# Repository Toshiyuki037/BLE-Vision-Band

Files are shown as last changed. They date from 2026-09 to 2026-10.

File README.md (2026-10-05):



<!-- BADGES -->

<p align="center">
  
  
  
  
</p>

<br />

<!-- TITLE -->

<div align="center">
  <h1>WBLE Vision Band</h1>
  <p><strong>Embedded BLE Vision System with Haptic Feedback</strong></p>

  <p>
    A wrist-mounted system that performs on-device image recognition and communicates results through real-time haptic feedback.
  </p>

  <br />

<a href="#">🎥 View Demo (Coming Soon)</a>

</div>

---

## 📌 Overview

Vision-Band is a wearable embedded system designed to explore on-device perception in resource-constrained environments.

Motivated by the limitations of the Even Realities G2 Frames—specifically the lack of an integrated camera—this project implements a modular vision pipeline paired with a haptic feedback interface for real-time, non-visual interaction.

---

## 🧠 System Architecture

```bash
[Camera] → [nRF5340 MCU] → [Processing / ML] → [DRV2605L] → [Vibration Motor]
                               ↓
                             [BLE]
```

* SPI camera streams image data to MCU
* MCU performs lightweight processing / inference
* Haptic driver converts results into vibration feedback
* BLE enables debugging + external communication

---

## 🔧 Hardware Components

* NRF5340-DK — main MCU + BLE
* Arducam Mega 5MP SPI Camera — image capture
* DRV2605L — haptic driver
* 3V vibration motor — feedback output
* Li-ion battery (500mAh) — power
* TP4056 — charging module

---

## DOCUMENTATION (BOM)

A dated and recorded log of all my research and development.
👉 https://app.notion.com/p/Vision-Band-3348546487d380519d59cf720e47a7b5

---

## 📦 Bill of Materials (BOM)

A detailed breakdown of all components, costs, and sourcing is available below:

👉 https://docs.google.com/spreadsheets/d/1EQedtdF9KUZCxSDgVT32OZnp6HhoeuN5VWY41QO01Ro/edit?usp=sharing

* Includes part numbers, suppliers, and prototyping cost (~$187)
* Documents full hardware stack for reproducibility

---

## ⚙️ Software Stack

* Embedded firmware (C/C++)
* SPI image acquisition pipeline
* I²C haptic control (DRV2605L)
* BLE communication (Nordic SDK)
* Lightweight image recognition (TinyML / rule-based)

---

## 🚀 Features

* On-device image capture and processing
* Real-time haptic feedback output
* BLE-enabled communication interface
* Fully self-contained wearable prototype
* End-to-end embedded system (hardware + firmware integration)

---

## 📊 Challenges & Engineering Tradeoffs

* **Memory constraints:** Limited RAM for image buffering
* **Bandwidth limits:** SPI camera throughput bottlenecks
* **Power system limitations:** TP4056 lacks load sharing
* **Compute vs latency:** Balancing ML accuracy and responsiveness

---

## 🔋 Power Considerations

* Powered by 3.7V Li-ion battery (500mAh)
* Charging via TP4056
* System currently optimized for prototyping, not all-day wearable use

---

## 🛠️ Getting Started

### Prerequisites

* Arduino IDE or Nordic SDK
* USB connection for NRF5340-DK
* Basic embedded development setup

### Installation

```bash
git clone https://github.com/Toshiyuki037/BLE-Vision-Band.git
```

1. Open firmware in IDE
2. Connect hardware components
3. Flash firmware to board
4. Power via battery + charging module

---

## 📁 Project Structure

```bash
/firmware      → Embedded code  
/hardware      → Schematics / BOM  
/docs          → Design notes  
```

---

## 🗺️ Roadmap

* [x] Hardware integration
* [x] Camera + MCU interface
* [ ] Image recognition optimization
* [ ] Power system redesign
* [ ] Custom PCB
* [ ] Wearable enclosure

---

## 📜 License

Distributed under the MIT License.

---

## 📬 Contact

GitHub: https://github.com/Toshiyuki037

Project Link:
https://github.com/Toshiyuki037/BLE-Vision-Band

---

<p align="center">↑ Back to top</p>

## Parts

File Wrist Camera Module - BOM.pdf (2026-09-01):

Assembly Name: Wrist Mounted Embedded BLE Image Recognition Module | Quantity Total: | 6
| Date: 4/23/26 | | | | | Prototyping Cost: 187.86
Final | Prototyping | Part ID | Part Name | URL | Quantity | Cost | BOM Notes
| * | KTO-M101949W | Micro DC Vibrating Motor : DC 3V | | 1 | 6.99 | ERM vibration motor; driven by DRV2605L
* | TP4056 | Type-C USB Charging Module 5V 1A | https://www.amazon.com/gp/product/B08FSRV7GS/ref=ox_sc_act_title_2?smid=A39S0U3UP1U7UG&th=1 1 | 5.99 | Li-ion charger; no load sharing/power path
* | RB-Adu-237 | Arducam Mega 5MP SPI Camera | https://www.amazon.com/gp/product/B0BW7MDVHK/ref=ox_sc_act_title_3?smid=A2IAB2RW3LLT8D&th=1 1 | 34.99 | SPI camera; requires downsampling + careful memory use
* | NRF5340-DK | Nordic Semiconductor Development Kit | https://www.amazon.com/gp/product/B0FCVL5JVT/ref=ox_sc_act_title_6?smid=A3N9748LE8DD6Y&psc=1 1 | 119.99 | Main MCU + BLE; dev board (not final form factor)
* | DRV2605L | Haptic Motor Controller | https://www.amazon.com/gp/product/B083G1MCYZ/ref=ox_sc_act_title_5?smid=A2KRDQ1AI5Y5G6&psc=1 1 | 11.95 | I²C haptic driver for vibration motor (ERM)
* | 1528-1841-ND | BATTERY LITH-ION 3.7V 500MAH | https://www.digikey.com/en/products/detail/adafruit-industries-llc/1578/5054539 1 | 7.95 | Main power source; limited runtime

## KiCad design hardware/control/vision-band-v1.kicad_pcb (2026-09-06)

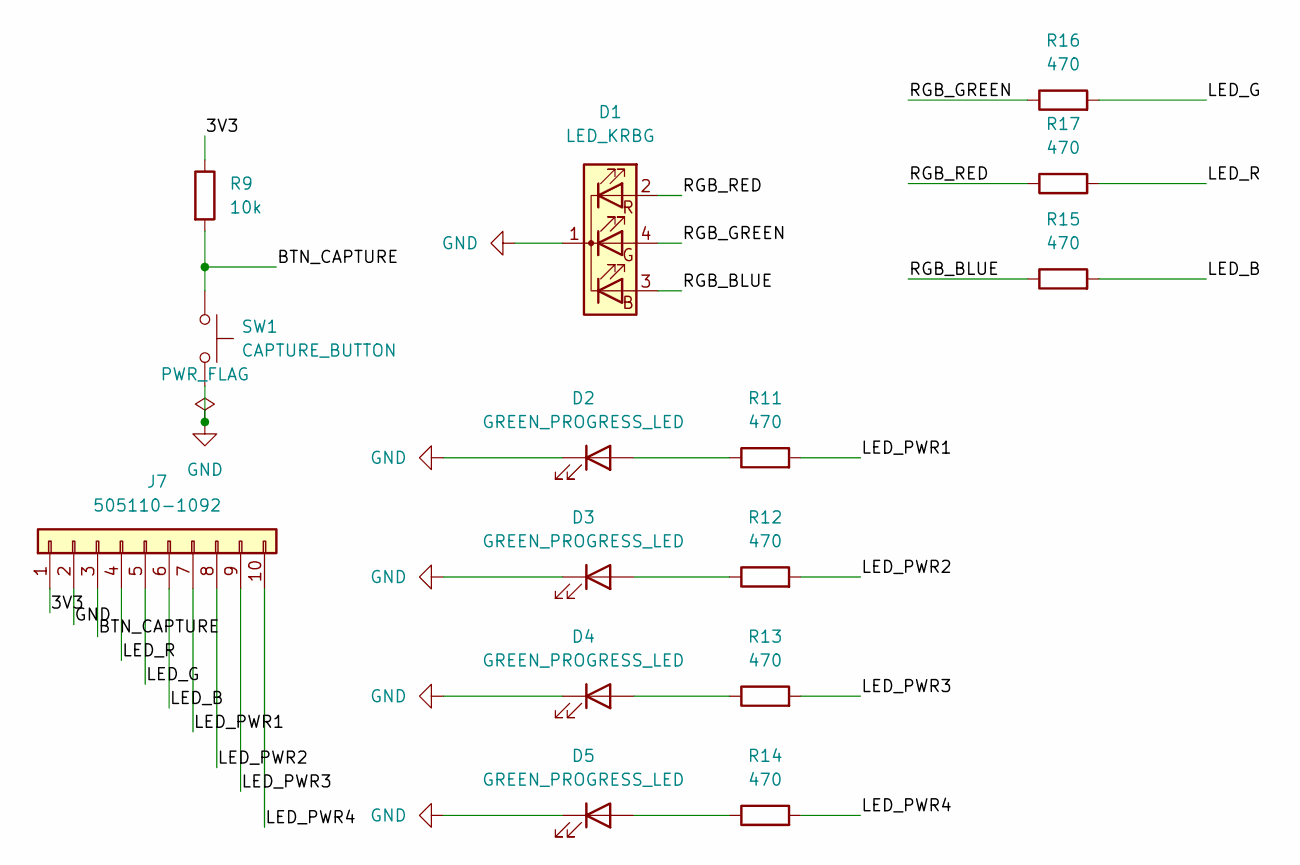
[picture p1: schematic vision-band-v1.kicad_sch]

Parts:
D1: LED_KRBG; APTF1616SEJ3ZGGVBDC_KNB; MPN APTF1616LSEKJ3ZGKQBC
D2, D3, D4, D5: GREEN_PROGRESS_LED; LED_0603_1608Metric; MPN APT1608LZGCK
J7: 505110-1092; MOLEX_5051101092; MPN 505110-1092
R9: 10k; R_0603_1608Metric; MPN RC0603FR-0710KL
R11, R12, R13, R14, R15, R16, R17: 470; R_0603_1608Metric; MPN RC0603FR-07470RL
SW1: CAPTURE_BUTTON; SW_SPST_TL3305A; MPN TL3305AF160QG

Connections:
/3V3: J7.1, R9.1
/BTN_CAPTURE: J7.3, R9.2, SW1.1
/LED_B: J7.6, R15.2
/LED_G: J7.5, R16.2
/LED_PWR1: J7.7, R11.2
/LED_PWR2: J7.8, R12.2
/LED_PWR3: J7.9, R13.2
/LED_PWR4: J7.10, R14.2
/LED_R: J7.4, R17.2
/RGB_BLUE: D1.3 (BA), R15.1
/RGB_GREEN: D1.4 (GA), R16.1
/RGB_RED: D1.2 (RA), R17.1
GND: D1.1 (K), D2.1 (K), D3.1 (K), D4.1 (K), D5.1 (K), J7.2, SW1.2
unnamed: D2.2 (A), R11.1
unnamed: D3.2 (A), R12.1
unnamed: D4.2 (A), R13.1
unnamed: D5.2 (A), R14.1

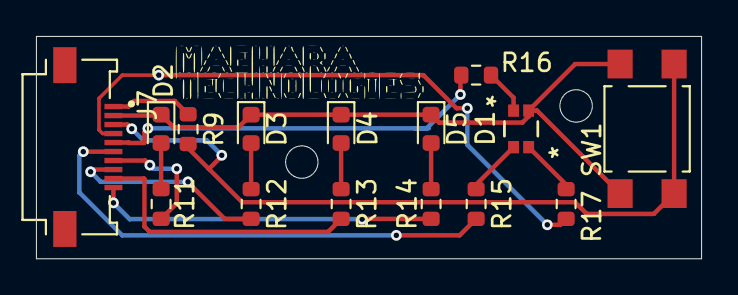
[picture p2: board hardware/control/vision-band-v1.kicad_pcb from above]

Board: 2 copper layers, 37.0 x 12.3 mm, 15 parts (0 on the bottom side), 17 nets.

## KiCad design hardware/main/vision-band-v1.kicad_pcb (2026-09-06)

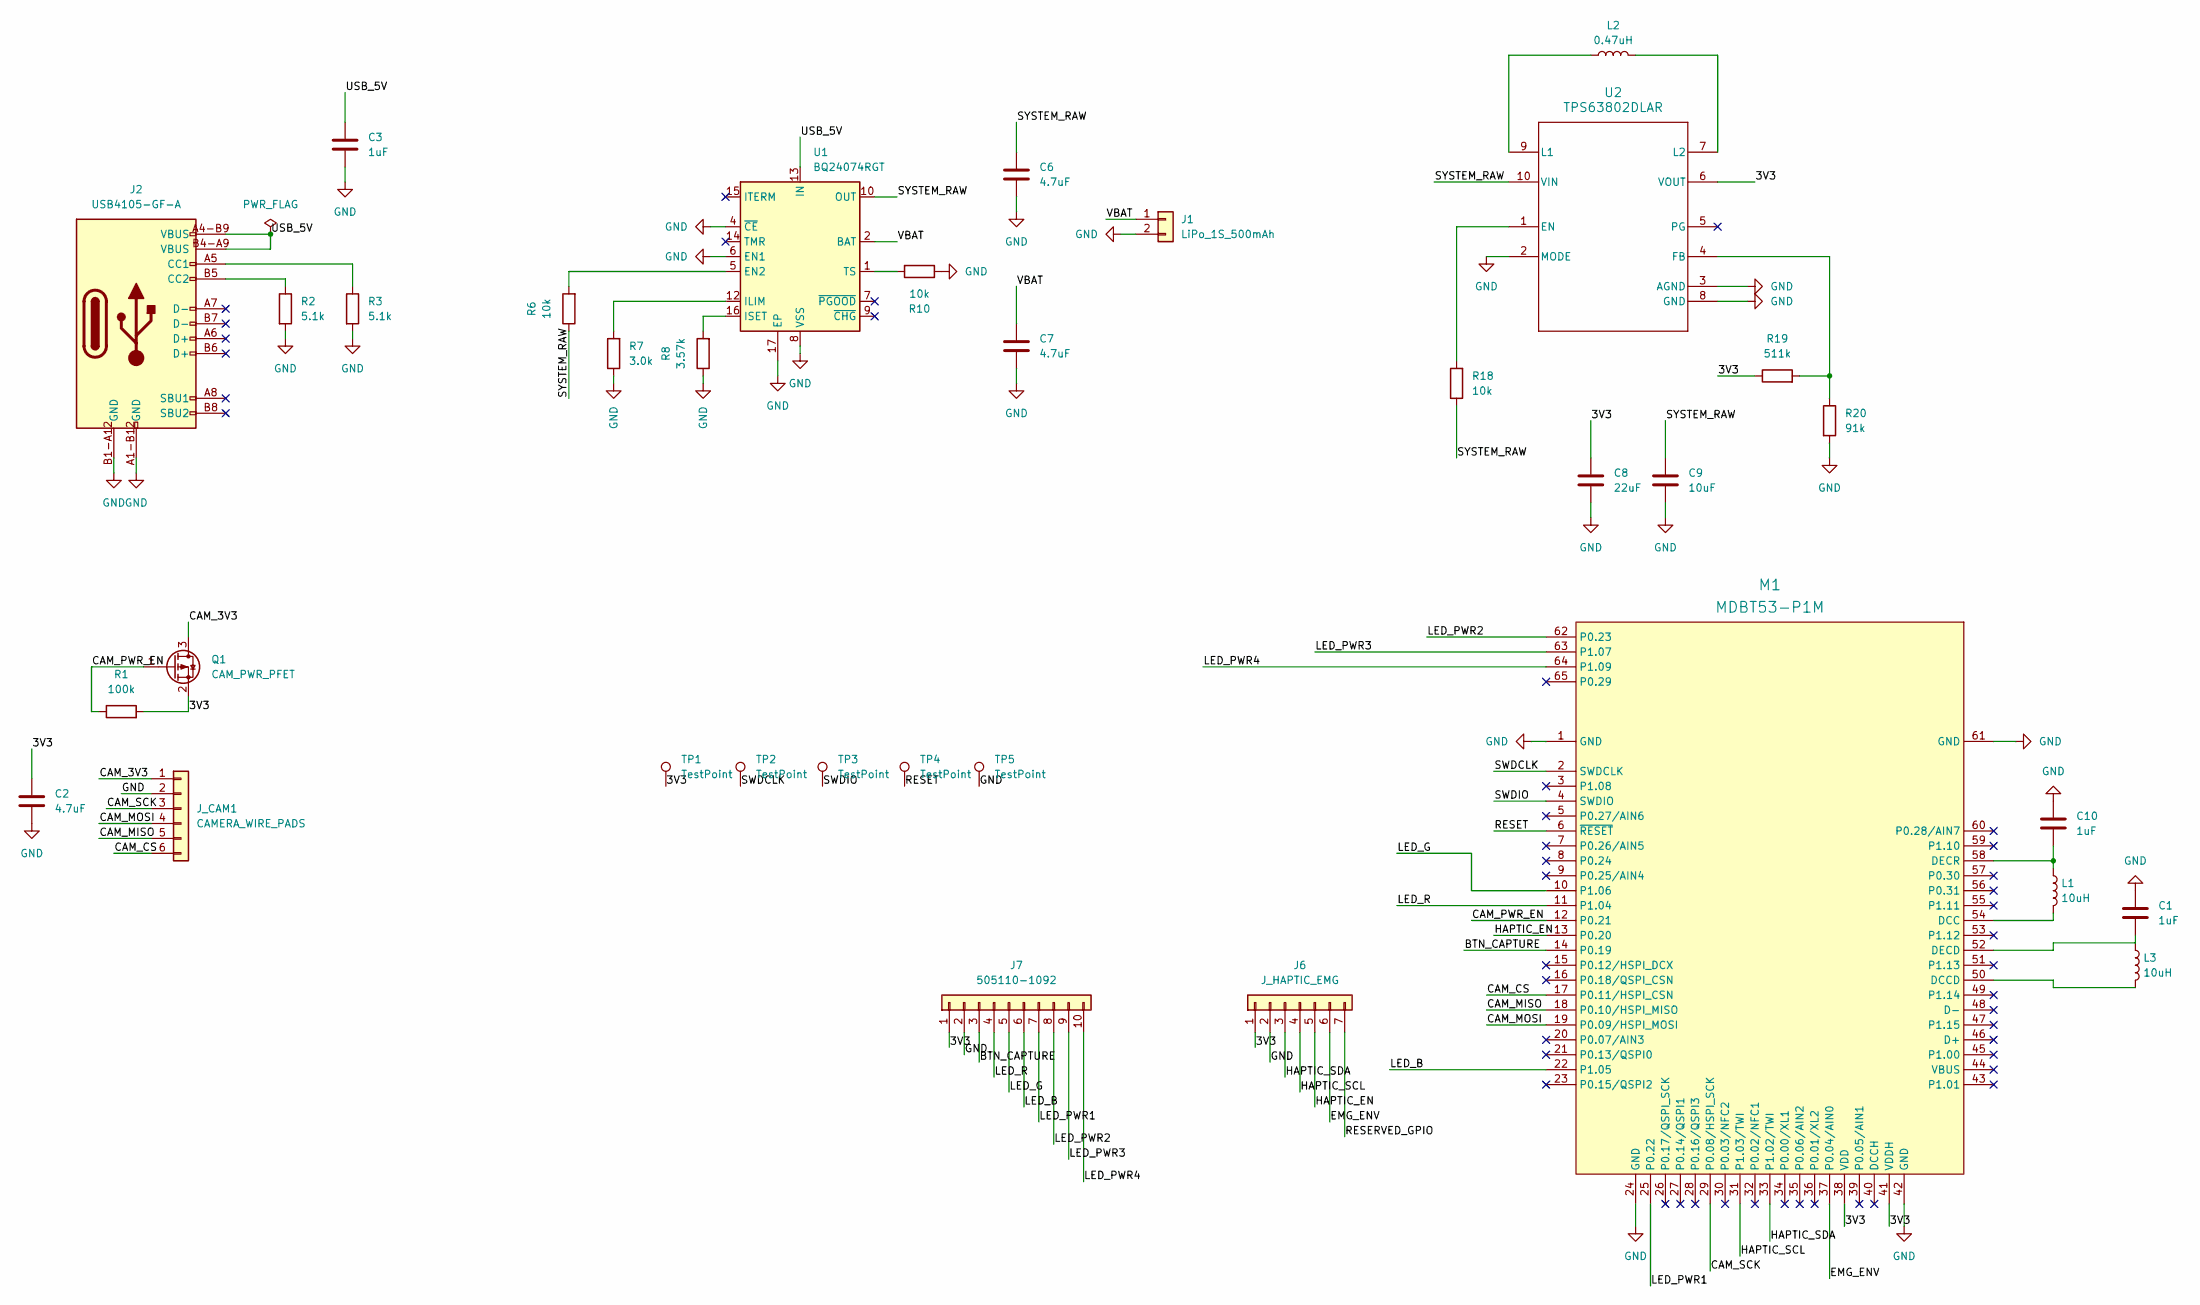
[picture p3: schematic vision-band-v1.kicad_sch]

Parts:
C1, C3, C10: 1uF; C_0603_1608Metric; MPN GRM188R71A105KA61J
C2, C6, C7: 4.7uF; C_0603_1608Metric; MPN GRM185R61A475KE11D
C8: 22uF; C_0805_2012Metric; MPN GRM21BR61A226ME51K
C9: 10uF; C_0603_1608Metric; MPN GRM188R61A106ME69D
J1: LiPo_1S_500mAh; JST_PH_S2B-PH-SM4-TB_1x02-1MP_P2.00mm_Horizontal; MPN S2B-PH-SM4-TB(LF)(SN)
J2: USB4105-GF-A; MPN USB4105-GF-A
J6: J_HAPTIC_EMG; TE_0-1734839-7_1x07-1MP_P0.5mm_Horizontal; MPN 0-1734839-7
J7: 505110-1092; MOLEX_5051101092; MPN 505110-1092
J_CAM1: CAMERA_WIRE_PADS; CAMERA_WIRE_PADS_2x3_P2.00mm
L1, L3: 10uH; L_0603_1608Metric; MPN 0603AF-103XJRW
L2: 0.47uH; DFE201612E-R47M; MPN DFE201612E-R47M=P2
M1: MDBT53-P1M; MPN MDBT53-P1M
Q1: CAM_PWR_PFET; SOT-23; MPN DMP2035U-7
R1: 100k; R_0603_1608Metric; MPN RC0603FR-07100KL
R2, R3: 5.1k; R_0603_1608Metric; MPN RC0603FR-075K1L
R6, R10, R18: 10k; R_0603_1608Metric; MPN RC0603FR-0710KL
R7: 3.0k; R_0603_1608Metric; MPN RC0603FR-073KL
R8: 3.57k; R_0603_1608Metric; MPN AC0603FR-073K57L
R19: 511k; R_0603_1608Metric; MPN RC0603FR-07511KL
R20: 91k; R_0603_1608Metric; MPN RC0603FR-0791KL
TP1, TP2, TP3, TP4, TP5: TestPoint; TestPoint_Pad_D1.0mm
U1: BQ24074RGT; BQ24074RGT_VQFN16_EP; MPN BQ24074RGT
U2: TPS63802DLAR; MPN TPS63802DLAR

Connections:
/3V3: C2.1, C8.1, J6.1, J7.1, M1.38 (VDD), M1.41 (VDDH), Q1.2 (S), R1.2, R19.1, TP1.1 (1_1), U2.6 (VOUT)
/BTN_CAPTURE: J7.3, M1.14 (P0.19)
/CAM_3V3: J_CAM1.1, Q1.3 (D)
/CAM_CS: J_CAM1.6, M1.17 (P0.11/HSPI_CSN)
/CAM_MISO: J_CAM1.5, M1.18 (P0.10/HSPI_MISO)
/CAM_MOSI: J_CAM1.4, M1.19 (P0.09/HSPI_MOSI)
/CAM_PWR_EN: M1.12 (P0.21), Q1.1 (G), R1.1
/CAM_SCK: J_CAM1.3, M1.29 (P0.08/HSPI_SCK)
/EMG_ENV: J6.6, M1.37 (P0.04/AIN0)
/HAPTIC_EN: J6.5, M1.13 (P0.20)
/HAPTIC_SCL: J6.4, M1.31 (P1.03/TWI)
/HAPTIC_SDA: J6.3, M1.33 (P1.02/TWI)
/LED_B: J7.6, M1.22 (P1.05)
/LED_G: J7.5, M1.10 (P1.06)
/LED_PWR1: J7.7, M1.25 (P0.22)
/LED_PWR2: J7.8, M1.62 (P0.23)
/LED_PWR3: J7.9, M1.63 (P1.07)
/LED_PWR4: J7.10, M1.64 (P1.09)
/LED_R: J7.4, M1.11 (P1.04)
/RESERVED_GPIO: J6.7
/RESET: M1.6 (~RESET), TP4.1 (1_1)
/SWDCLK: M1.2 (SWDCLK), TP2.1 (1_1)
/SWDIO: M1.4 (SWDIO), TP3.1 (1_1)
/SYSTEM_RAW: C6.1, C9.1, R6.1, R18.1, U1.10 (OUT), U1.11 (OUT), U2.10 (VIN)
/USB_5V: C3.1, J2.A4-B9 (VBUS), J2.B4-A9 (VBUS), U1.13 (IN)
/VBAT: C7.1, J1.1, U1.2 (BAT), U1.3 (BAT)
GND: C1.1, C2.2, C3.2, C6.2, C7.2, C8.2, C9.2, C10.1, J1.2, J2.A1-B12 (GND), J2.B1-A12 (GND), J6.2, J7.2, J_CAM1.2, M1.1 (GND), M1.24 (GND), M1.42 (GND), M1.61 (GND), R2.2, R3.2, R7.1, R8.1, R10.1, R20.2, TP5.1 (1_1), U1.4 (~CE), U1.6 (EN1), U1.8 (VSS), U1.17 (EP), U2.2 (MODE), U2.3 (AGND), U2.8 (GND)
unnamed: J2.A5 (CC1), R3.1
unnamed: J2.B5 (CC2), R2.1
unnamed: L1.2, M1.54 (DCC)
unnamed: L3.2, M1.50 (DCCD)
unnamed: C1.2, L3.1, M1.52 (DECD)
unnamed: C10.2, L1.1, M1.58 (DECR)
unnamed: R6.2, U1.5 (EN2)
unnamed: R7.2, U1.12 (ILIM)
unnamed: R8.2, U1.16 (ISET)
unnamed: R10.2, U1.1 (TS)
unnamed: R18.2, U2.1 (EN)
unnamed: R19.2, R20.1, U2.4 (FB)
unnamed: L2.1, U2.9 (L1)
unnamed: L2.2, U2.7 (L2)

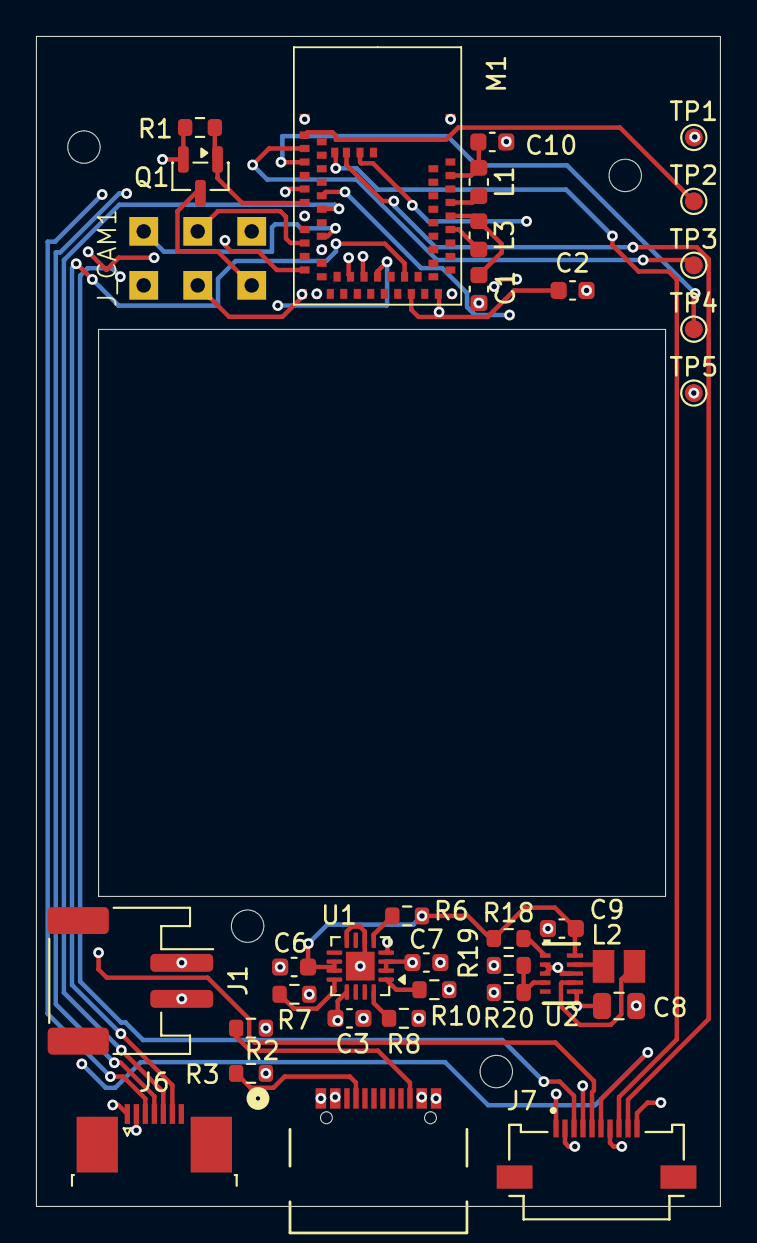
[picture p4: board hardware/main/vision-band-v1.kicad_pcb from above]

Board: 4 copper layers, 38.0 x 65.0 mm, 35 parts (0 on the bottom side), 40 nets.

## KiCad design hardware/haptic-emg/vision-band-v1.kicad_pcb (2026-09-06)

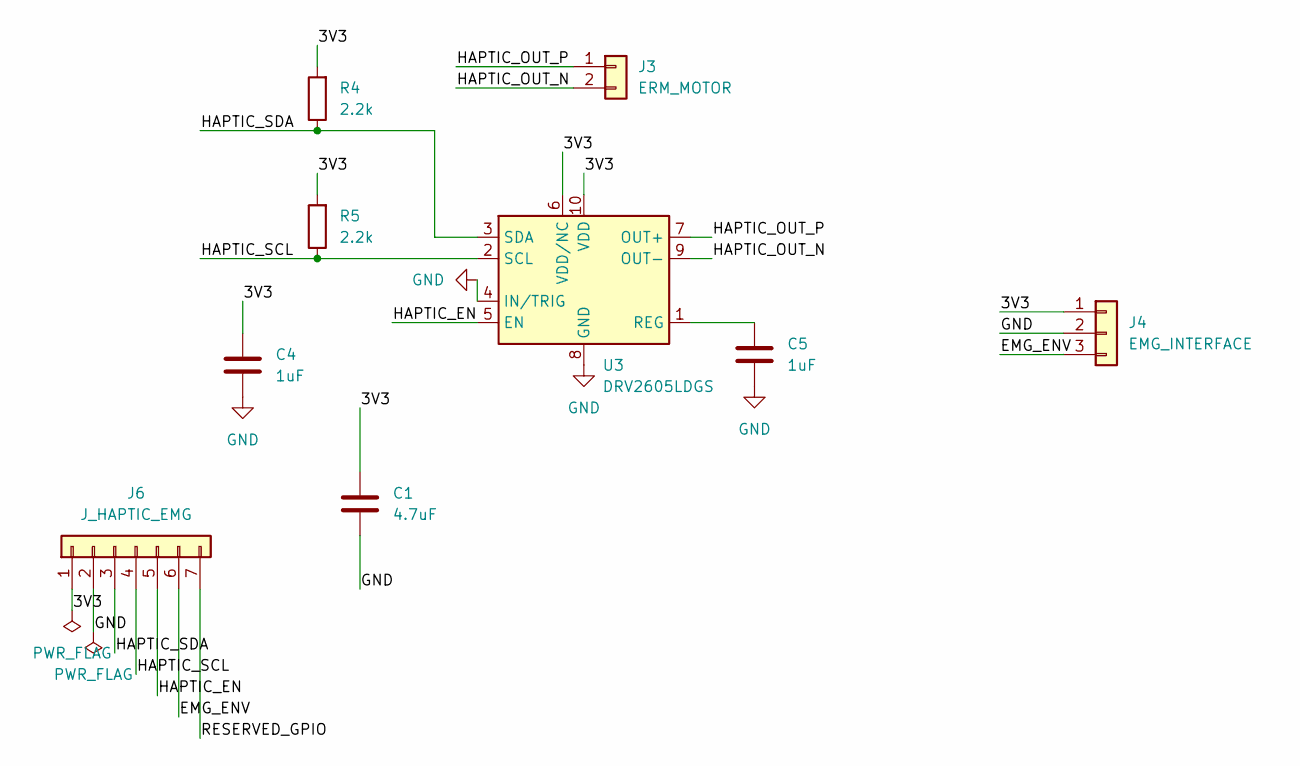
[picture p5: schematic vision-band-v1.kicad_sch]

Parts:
C1: 4.7uF; C_0603_1608Metric; MPN GRM185R61A475KE11D
C4, C5: 1uF; C_0603_1608Metric; MPN GRM188R71A105KA61J
J3: ERM_MOTOR; SolderWire-0.5sqmm_1x02_P4.6mm_D0.9mm_OD2.1mm_Relief
J4: EMG_INTERFACE; JST_SH_SM03B-SRSS-TB_1x03-1MP_P1.00mm_Horizontal; MPN SM03B-SRSS-TB(LF)(SN)
J6: J_HAPTIC_EMG; TE_0-1734839-7_1x07-1MP_P0.5mm_Horizontal; MPN 0-1734839-7
R4, R5: 2.2k; R_0603_1608Metric; MPN RC0603FR-072K2L
U3: DRV2605LDGS; TSSOP-10_3x3mm_P0.5mm; MPN DRV2605LDGSR

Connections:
/3V3: C1.1, C4.1, J4.1, J6.1, R4.2, R5.2, U3.6 (VDD/NC), U3.10 (VDD)
/EMG_ENV: J4.3, J6.6
/HAPTIC_EN: J6.5, U3.5 (EN)
/HAPTIC_OUT_N: J3.2, U3.9 (OUT-)
/HAPTIC_OUT_P: J3.1, U3.7 (OUT+)
/HAPTIC_SCL: J6.4, R5.1, U3.2 (SCL)
/HAPTIC_SDA: J6.3, R4.1, U3.3 (SDA)
/RESERVED_GPIO: J6.7
GND: C1.2, C4.2, C5.2, J4.2, J6.2, U3.4 (IN/TRIG), U3.8 (GND)
unnamed: C5.1, U3.1 (REG)

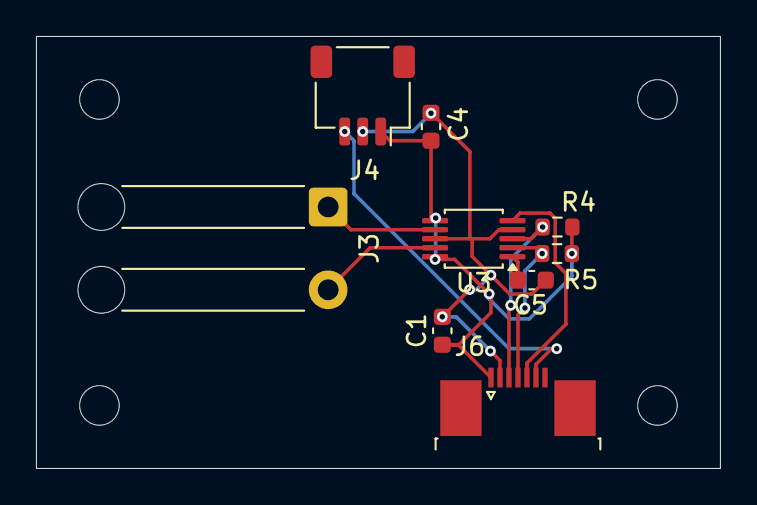
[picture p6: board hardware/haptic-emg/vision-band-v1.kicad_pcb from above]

Board: 2 copper layers, 38.0 x 24.0 mm, 9 parts (0 on the bottom side), 9 nets.

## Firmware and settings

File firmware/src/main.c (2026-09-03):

#include <zephyr/kernel.h>
#include <zephyr/sys/printk.h>
#include <zephyr/device.h>
#include <zephyr/drivers/gpio.h>

#include <stdbool.h>
#include <string.h>

#include "power_leds.h"
#include "rgb_led.h"
#include "camera.h"
#include "ble_service.h"
#include "haptics.h"


#define BUTTON_NODE DT_ALIAS(sw0)

static const struct gpio_dt_spec button =
    GPIO_DT_SPEC_GET(BUTTON_NODE, gpios);


#define POLL_MS               10
#define DEBOUNCE_MS           40
#define POWER_PROGRESS_MS     250
#define FULL_HOLD_MS          1500
#define RELEASE_DEBOUNCE_MS   120
#define POWER_ACTION_LOCKOUT_MS 400


static bool system_on = false;
static int64_t capture_lockout_until = 0;


static void wait_for_stable_button_release(void)
{
    int64_t released_at = 0;

    while (1) {

        if (!gpio_pin_get_dt(&button)) {

            if (released_at == 0) {
                released_at = k_uptime_get();
            }

            if ((k_uptime_get() - released_at) >= RELEASE_DEBOUNCE_MS) {
                return;
            }

        }
        else {
            released_at = 0;
        }

        k_msleep(POLL_MS);
    }
}


/*
 * ------------------------------------------------------------------
 * BLE connection-state callback.
 *
 * The RGB status LED is only allowed to show BLE state while the
 * logical Vision Band power state is ON.
 *
 * OFF   -> RGB off
 * ON + disconnected -> white
 * ON + connected    -> blue
 * ------------------------------------------------------------------
 */
static void handle_ble_connection_changed(bool connected)
{
    if (!system_on) {

        rgb_led_off();

        return;
    }


    if (connected) {

        rgb_led_blue();

        printk(
            "Status LED: BLUE (BLE connected)\n"
        );

        /*
         * Phase 6D:
         * Connection confirmation is queued to the dedicated haptic
         * worker thread. It never blocks the BLE callback.
         */
        (void)haptics_play(
            HAPTIC_EVENT_BLE_CONNECTED
        );
    }
    else {

        rgb_led_white();

        printk(
            "Status LED: WHITE (BLE disconnected)\n"
        );
    }
}



/*
 * ------------------------------------------------------------------
 * BLE -> product control bridge.
 *
 * Phase 7B return path:
 *
 * Windows/OpenAI
 *      -> CONTROL_RX "RESULT_READY"
 *      -> ble_service.c
 *      -> this callback
 *      -> asynchronous DRV2605L result-ready haptic
 *
 * This callback executes from the BLE receive context, so it only
 * queues haptic work and returns immediately.
 * ------------------------------------------------------------------
 */
static void handle_ble_command(
    const uint8_t *data,
    size_t length
)
{
    static const char result_ready_command[] =
        "RESULT_READY";


    if (
        length ==
            (sizeof(result_ready_command) - 1) &&
        memcmp(
            data,
            result_ready_command,
            sizeof(result_ready_command) - 1
        ) == 0
    ) {

        printk(
            "BLE command RESULT_READY received\n"
        );

        (void)haptics_play(
            HAPTIC_EVENT_RESULT_READY
        );

        return;
    }


    printk(
        "BLE product command not recognized (%u bytes)\n",
        (unsigned int)length
    );
}


/*
 * ------------------------------------------------------------------
 * Camera -> BLE transport bridge.
 *
 * Camera code knows nothing about GATT.
 * BLE code knows nothing about Arducam.
 * main.c connects the two subsystems.
 * ------------------------------------------------------------------
 */

static int camera_ble_begin(
    uint32_t fifo_length,
    void *context
)
{
    ARG_UNUSED(context);

    return ble_service_image_begin(
        fifo_length
    );
}


static int camera_ble_write(
    const uint8_t *data,
    size_t length,
    void *context
)
{
    ARG_UNUSED(context);

    return ble_service_image_send(
        data,
        length
    );
}


static int camera_ble_end(
    uint32_t jpeg_length,
    void *context
)
{
    ARG_UNUSED(context);

    return ble_service_image_end(
        jpeg_length
    );
}


/*
 * Called by camera.c only after autofocus + sensor capture are complete
 * and a valid JPEG exists in the Arducam FIFO, but before BLE upload.
 *
 * This haptic means exactly: "PHOTO CAPTURED — you can move now."
 */
static void camera_ble_capture_complete(
    void *context
)
{
    ARG_UNUSED(context);

    printk(
        "PHOTO CAPTURED: JPEG is ready in camera FIFO\n"
    );

    (void)haptics_play(
        HAPTIC_EVENT_PHOTO_CAPTURED
    );
}


static const struct camera_stream_sink ble_camera_sink = {
    .begin = camera_ble_begin,
    .write = camera_ble_write,
    .capture_complete = camera_ble_capture_complete,
    .end = camera_ble_end,
    .context = NULL
};


/*
 * ------------------------------------------------------------------
 * Capture one image only when the Vision Band is logically powered on.
 *
 * The camera itself is initialized once at boot. A short BUTTON1 press
 * while system_on == true performs:
 *
 *      autofocus -> one 5MP capture -> JPEG stream over BLE
 *
 * No boot-time capture is performed.
 * ------------------------------------------------------------------
 */
static void handle_short_press(void)
{
    int ret;

    if (k_uptime_get() < capture_lockout_until) {

        printk(
            "Short press ignored: power transition lockout\n"
        );

        return;
    }

    if (!system_on) {

        printk(
            "Short press ignored: system is OFF\n"
        );

        power_leds_off();
        rgb_led_off();

        return;
    }


    if (!ble_service_is_connected()) {

        printk(
            "Capture ignored: BLE central is not connected\n"
        );

        (void)haptics_play(
            HAPTIC_EVENT_ERROR
        );

        return;
    }


    if (!ble_service_image_ready()) {

        printk(
            "Capture ignored: BLE image receiver is not subscribed\n"
        );

        (void)haptics_play(
            HAPTIC_EVENT_ERROR
        );

        return;
    }


    /*
     * Keep the ON indicators asserted while the camera is working.
     */
    power_leds_all_on();
    rgb_led_blue();


    printk(
        "BUTTON1 short press: starting BLE camera capture\n"
    );

    ret =
        camera_capture_and_stream(
            &ble_camera_sink
        );

    if (ret < 0) {

        printk(
            "Camera capture/export failed: %d\n",
            ret
        );

        (void)haptics_play(
            HAPTIC_EVENT_ERROR
        );

        /*
         * The logical system remains ON even if a capture fails.
         */
        power_leds_all_on();

        if (ble_service_is_connected()) {

            rgb_led_blue();
        }
        else {

            rgb_led_white();
        }

        return;
    }


    printk(
        "Camera JPEG BLE transfer complete\n"
    );

    /*
     * Restore normal powered-on indicators.
     */
    power_leds_all_on();

    if (ble_service_is_connected()) {

        rgb_led_blue();
    }
    else {

        rgb_led_white();
    }
}


int main(void)
{
    int64_t press_start;
    int64_t held_ms;
    bool long_press_handled;


    /*
     * ==============================================================
     * Power LEDs
     * ==============================================================
     */

    if (power_leds_init() < 0) {

        printk(
            "Power LED init failed\n"
        );

        return 0;
    }


    /*
     * ==============================================================
     * RGB status LED
     * ==============================================================
     */

    if (rgb_led_init() < 0) {

        printk(
            "Status LED init failed\n"
        );

        return 0;
    }


    /*
     * ==============================================================
     * Haptics
     * ==============================================================
     *
     * The DRV2605L worker owns vibration timing on its own Zephyr
     * thread. Camera/BLE code only enqueue semantic haptic events.
     */

    if (haptics_init() < 0) {

        /*
         * Haptics are user feedback, not a prerequisite for camera/BLE
         * operation. Keep the rest of the Vision Band alive if the
         * motor driver is temporarily unavailable.
         */
        printk(
            "Haptics init failed; continuing without vibration\n"
        );
    }


    /*
     * ==============================================================
     * Camera initialization
     * ==============================================================
     *
     * Initialize the camera interface once at firmware startup.
     * Do NOT capture here.
     *
     * Actual image capture is triggered later by a short BUTTON1
     * press, and only while system_on == true.
     */

    if (camera_init() < 0) {

        printk(
            "Camera init failed\n"
        );

        return 0;
    }


    printk(
        "Camera interface initialized\n"
    );


    /*
     * ==============================================================
     * Bluetooth
     * ==============================================================
     */

    if (
        ble_service_init(
            handle_ble_connection_changed,
            handle_ble_command
        ) < 0
    ) {

        /*
         * BLE failure must not kill the button/camera runtime.
         * The Vision Band can still operate locally.
         */
        printk(
            "BLE init failed; continuing without BLE\n"
        );
    }


    /*
     * ==============================================================
     * Button
     * ==============================================================
     */

    if (!gpio_is_ready_dt(&button)) {

        printk(
            "Button device not ready\n"
        );

        return 0;
    }


    if (
        gpio_pin_configure_dt(
            &button,
            GPIO_INPUT
        ) < 0
    ) {

        printk(
            "Button configuration failed\n"
        );

        return 0;
    }


    /*
     * Initial logical system state.
     */
    system_on = false;

    power_leds_off();
    rgb_led_off();


    printk(
        "Vision Band controller ready\n"
    );

    printk(
        "System state: OFF\n"
    );

    printk(
        "Long press BUTTON1: power ON/OFF\n"
    );

    printk(
        "Short press BUTTON1 while ON: capture image\n"
    );


    /*
     * ==============================================================
     * Main runtime
     * ==============================================================
     */

    while (1) {


        if (gpio_pin_get_dt(&button)) {

            press_start =
                k_uptime_get();

            long_press_handled =
                false;


            /*
             * Button remains pressed.
             */
            while (
                gpio_pin_get_dt(&button)
            ) {

                held_ms =
                    k_uptime_get()
                    -
                    press_start;


                /*
                 * Do not start the power animation immediately.
                 *
                 * This prevents a normal short camera press from
                 * visibly draining/filling the power LEDs.
                 */
                if (
                    held_ms >=
                    POWER_PROGRESS_MS
                ) {

                    /*
                     * OFF -> fill LEDs.
                     */
                    if (!system_on) {

                        power_leds_show_power_on_progress(
                            held_ms
                        );
                    }

                    /*
                     * ON -> drain LEDs.
                     */
                    else {

                        power_leds_show_power_off_progress(
                            held_ms
                        );
                    }
                }


                /*
                 * Long press reached: toggle logical power state.
                 */
                if (
                    held_ms >=
                    FULL_HOLD_MS
                ) {

                    long_press_handled =
                        true;


                    if (!system_on) {

                        system_on =
                            true;

                        power_leds_all_on();
                        rgb_led_white();


                        printk(
                            "System state: ON\n"
                        );

                        printk(
                            "Camera short-press capture enabled\n"
                        );


                        /*
                         * Logical power ON is what makes the product
                         * discoverable/connectable over BLE.
                         */
                        if (
                            ble_service_start() < 0
                        ) {

                            printk(
                                "BLE could not start; local operation remains available\n"
                            );
                        }
                    }
                    else {

                        /*
                         * Set logical power OFF before requesting the
                         * BLE disconnect so its callback keeps the RGB
                         * LED off and does not restart advertising.
                         */
                        system_on =
                            false;


                        (void)ble_service_stop();


                        power_leds_off();
                        rgb_led_off();


                        printk(
                            "System state: OFF\n"
                        );

                        printk(
                            "Camera short-press capture disabled\n"
                        );
                    }


                    /*
                     * Do not let the release/bounce from a power hold
                     * become a camera short press.
                     */
                    wait_for_stable_button_release();

                    capture_lockout_until =
                        k_uptime_get()
                        +
                        POWER_ACTION_LOCKOUT_MS;


                    break;
                }


                k_msleep(
                    POLL_MS
                );
            }


            /*
             * If the press did not become a long press, it is a
             * short-press action.
             */
            if (!long_press_handled) {

                held_ms =
                    k_uptime_get()
                    -
                    press_start;


                /*
                 * Ignore switch bounce / accidental ultra-short pulses.
                 */
                if (
                    held_ms >=
                    DEBOUNCE_MS
                ) {

                    handle_short_press();
                }
                else {

                    /*
                     * Restore whichever visual state was active.
                     */
                    if (system_on) {

                        power_leds_all_on();

                        if (ble_service_is_connected()) {

                            rgb_led_blue();
                        }
                        else {

                            rgb_led_white();
                        }
                    }
                    else {

                        power_leds_off();
                        rgb_led_off();
                    }
                }
            }


            /*
             * Small post-release debounce.
             */
            k_msleep(
                50
            );
        }


        k_msleep(
            POLL_MS
        );
    }


    return 0;
}

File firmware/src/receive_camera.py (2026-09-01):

from __future__ import annotations

import re
import sys
import time
from pathlib import Path

import serial


PORT = "COM4"
BAUD = 115200
READ_TIMEOUT_S = 0.20
TRANSFER_STALL_TIMEOUT_S = 15.0
POST_JPEG_CONSOLE_DRAIN_S = 2.0

BEGIN_PREFIX = b"JPEG_BINARY_BEGIN:"
MAX_SYNC_BUFFER = 8192
MAX_JPEG_SIZE = 16 * 1024 * 1024

OUTPUT_PATH = Path(__file__).resolve().parents[2] / "capture.jpg"


def print_clean_console_bytes(chunk: bytes, line_buffer: bytearray) -> None:
    """
    Before the JPEG marker arrives, print only clean ASCII console lines.
    Binary-looking data is discarded instead of dumping gibberish.
    """
    for b in chunk:
        if b in (10, 13):
            if line_buffer:
                try:
                    line = line_buffer.decode("ascii")
                except UnicodeDecodeError:
                    line = ""

                if line and all(ch.isprintable() or ch == "\t" for ch in line):
                    print(line)

                line_buffer.clear()

        elif 32 <= b <= 126 or b == 9:
            if len(line_buffer) < 300:
                line_buffer.append(b)

        else:
            line_buffer.clear()


def extract_begin_marker(buffer: bytearray):
    start = buffer.find(BEGIN_PREFIX)
    if start < 0:
        return None

    newline = buffer.find(b"\n", start)
    if newline < 0:
        return None

    marker = bytes(buffer[start:newline]).rstrip(b"\r")
    match = re.fullmatch(rb"JPEG_BINARY_BEGIN:(\d+)", marker)

    if not match:
        del buffer[: newline + 1]
        return None

    announced_length = int(match.group(1))
    remainder = bytes(buffer[newline + 1 :])

    return announced_length, remainder


def wait_for_begin_marker(ser: serial.Serial):
    sync = bytearray()
    line_buffer = bytearray()

    while True:
        chunk = ser.read(512)

        if not chunk:
            continue

        sync.extend(chunk)

        result = extract_begin_marker(sync)
        if result is not None:
            return result

        print_clean_console_bytes(chunk, line_buffer)

        if len(sync) > MAX_SYNC_BUFFER:
            keep = max(len(BEGIN_PREFIX) + 64, 128)
            del sync[:-keep]


def find_complete_jpeg(data: bytes):
    """
    Return (jpeg_bytes, soi_offset, eoi_offset) once a complete JPEG exists.

    The Arducam FIFO length may include bytes after JPEG EOI (FF D9).
    Those bytes are not part of the image and must not be required before
    declaring the transfer successful.
    """
    soi = data.find(b"\xFF\xD8")
    if soi < 0:
        return None

    eoi = data.find(b"\xFF\xD9", soi + 2)
    if eoi < 0:
        return None

    jpeg = data[soi : eoi + 2]
    return jpeg, soi, eoi


def receive_until_jpeg_complete(
    ser: serial.Serial,
    announced_length: int,
    initial_data: bytes,
):
    data = bytearray(initial_data)

    if len(data) > announced_length:
        data = data[:announced_length]

    last_data_time = time.monotonic()
    next_report = 10

    while True:
        complete = find_complete_jpeg(data)

        if complete is not None:
            jpeg, soi, eoi = complete
            return jpeg, len(data), soi, eoi

        if len(data) >= announced_length:
            raise ValueError(
                "Received the full announced FIFO payload, "
                "but no JPEG EOI marker FF D9 was found"
            )

        chunk = ser.read(min(4096, announced_length - len(data)))

        if chunk:
            data.extend(chunk)
            last_data_time = time.monotonic()

            percent = (len(data) * 100) // announced_length

            if percent >= next_report:
                print(
                    f"Receiving: {len(data)}/{announced_length} bytes "
                    f"({percent}%)"
                )

                while next_report <= percent:
                    next_report += 10

        else:
            if time.monotonic() - last_data_time > TRANSFER_STALL_TIMEOUT_S:
                # One final check before reporting a true failure.
                complete = find_complete_jpeg(data)

                if complete is not None:
                    jpeg, soi, eoi = complete
                    return jpeg, len(data), soi, eoi

                raise TimeoutError(
                    "JPEG transfer stalled before EOI marker: "
                    f"{len(data)}/{announced_length} bytes"
                )



def drain_post_jpeg_console(ser: serial.Serial) -> None:
    """
    Keep COM4 open briefly after FF D9 so firmware can finish its
    remaining FIFO/padding transmission and print its completion log.
    """
    deadline = time.monotonic() + POST_JPEG_CONSOLE_DRAIN_S
    line_buffer = bytearray()

    while time.monotonic() < deadline:
        chunk = ser.read(512)

        if not chunk:
            continue

        print_clean_console_bytes(chunk, line_buffer)
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

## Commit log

2026-09-01 feat: add RGB status LED support
2026-09-01 feat: add power LED animations and status indicator
2026-09-01 feat: complete button-triggered 5MP camera pipeline
2026-09-01 feat: gate BLE lifecycle to device power state
2026-09-06 Add Vision Band V1 PCB hardware designs
    [vision-band-v1.kicad_pcb, vision-band-v1.kicad_sch]
